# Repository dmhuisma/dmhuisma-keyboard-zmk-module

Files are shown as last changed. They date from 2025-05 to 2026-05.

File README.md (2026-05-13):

# Dmhuisma Keyboard ZMK Module

This is my ZMK module for the split keyboard I generated with the [Cosmos keyboard generator](https://ryanis.cool/cosmos/). This is version 2 of the keyboard ([version 1](https://github.com/dmhuisma/dmhuisma-keyboard-zmk-module/tree/v1) is shown in the image below as I have not built it yet). After I built [Splitcore](https://github.com/dmhuisma/splitcore-zmk) I found that I never used this one, so I decided to repurpose its parts into something new.

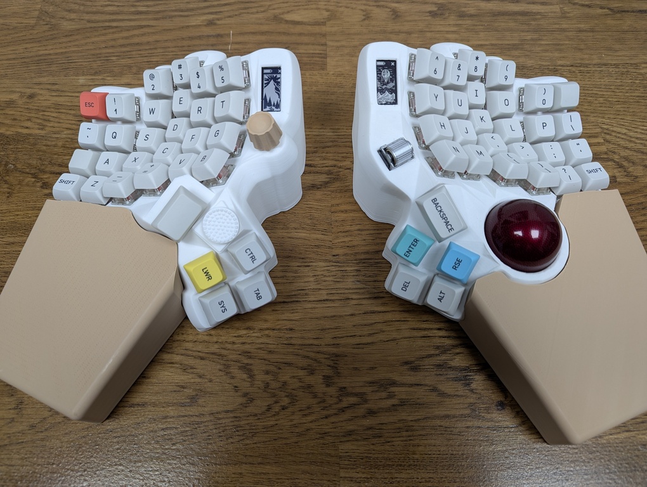
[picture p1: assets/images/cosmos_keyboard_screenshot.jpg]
Cosmos Keyboard Screenshot


The cosmos generator configuration is saved in the URL, here is [my configuration](https://ryanis.cool/cosmos/beta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).

## Features
- Ergonomic
    - Split
    - Concave key well
    - Thumb clusters
    - Staggered to accommodate my hand/finger sizes
- Trackpad
- Display
- Hotswappable keys
- Potentiometer (with directional clicking) for media controls.
- [Custom DPAD](https://github.com/dmhuisma/1u_mx_dpad) on the left side for cursor navigation or gaming.

## Building

The firmware is built by Github actions on every commit. It can also be built with a local install of ZMK with the following commands.

> west build -p auto -d build/left -b nice_nano//zmk -- -DZMK_EXTRA_MODULES="[path to module]/dmhuisma-zmk;[path to module]/zmk_arbitrary_split_data_channel;[path to module]/zmk-split-status-relay;/[path to module]/nice-view-peripheral" -DSHIELD="dmhuisma_left nice_view_peripheral"

> west build -p auto -d build/right -b nice_nano//zmk -- -DZMK_EXTRA_MODULES="[path to module]/dmhuisma-zmk;[path to module]/zmk-driver-azoteq-iqs5xx;[path to module]/zmk_arbitrary_split_data_channel;[path to module]/zmk-split-status-relay;" -DSHIELD="dmhuisma_right"

> west build -p auto -d build/dongle -b nrf52840_mdk_usb_dongle -- -DZMK_EXTRA_MODULES="[path to module]/dmhuisma-zmk;/[path to module]/zmk-pointing-acceleration-alpha;[path to module]/zmk_arbitrary_split_data_channel;[path to module]/zmk-split-status-relay" -DSHIELD="dmhuisma_dongle"

If building locally, the following external zmk modules are required on your machine:

- [zmk-driver-azoteq-iqs5xx](https://github.com/AYM1607/zmk-driver-azoteq-iqs5xx)
- [zmk-pointing-acceleration-alpha](https://github.com/nuovotaka/zmk-pointing-acceleration-alpha)
- [zmk-arbitrary-split-data-channel](https://github.com/dmhuisma/zmk_arbitrary_split_data_channel)
- [zmk-split-status-relay](https://github.com/dmhuisma/zmk-split-status-relay)
- [nice-view-battery-peripheral](https://github.com/dmhuisma/nice-view-battery-peripheral)

## Pinout

This keyboard uses the [nice!nano V2](https://nicekeyboards.com/nice-nano/) on each side. However, there is not enough GPIO pins for this keyboard, so it also uses shift registers (74HC595) for the output pins.

### Left Keyboard

#### Nice!Nano V2 Left Side GPIO
| | |
|---|---|
|Battery- ||
|**[D1]** P0.06 |RKJXT1F42001 Encoder A|
|**[D0]** P0.08 |RKJXT1F42001 Encoder B|
|GND |NiceView GND|
|GND |DPAD GND, RKJXT1F42001 GND|
|**[D2]** P0.17 |NiceView MOSI|
|**[D3]** P0.20 |RKJXT1F42001 down|
|**[D4]** P0.22 |NiceView SCK|
|**[D5]** P0.24 |74HC595 SCK|
|**[D6]** P1.00 |74HC595 MOSI|
|**[D7]** P0.11 |DPAD Up|
|**[D8]** P1.04 |DPAD Down|
|**[D9]** P1.06 |Column 4|

#### Nice!Nano V2 Right Side GPIO
| | |
|---|---|
|Battery+ ||
|Battery+ ||
|GND |74HC595 GND, 74HC595 OE|
|Reset ||
|3.3V Vcc |NiceView Vcc, 74HC595 Vcc|
|**[D21]** P0.31 (ADC)  |Row 0|
|**[D20]** P0.29 (ADC)  |Row 1|
|**[D19]** P0.02 (ADC)  |Row 2|
|**[D18]** P1.15 |Row 3|
|**[D15]** P1.13 |74HC595 CS/RCLK|
|**[D14]** P1.11 |NiceView CS|
|**[D16]** P0.10 |DPAD Left|
|**[D10]** P0.09 |DPAD Right|

#### Nice!Nano V2 Back GPIO
| | |
|---|---|
|P1.01 |RKJXT1F42001 left|
|P1.02 |RKJXT1F42001 right|
|P1.07 |Row 4|

#### Shift Register (74HC595) GPIO
| | |
|---|---|
|QA |Column 0|
|QB |Column 1|
|QC |Column 2|
|QD |Column 3|
|QE ||
|QF |Column 5|
|QG |Column 6|
|QH |Column 7|
|QH` ||

### Right Keyboard

#### Nice!Nano V2 Left Side GPIO
| | |
|---|---|
|Battery+ ||
|**[D1]** P0.06 |Trackpad reset|
|**[D0]** P0.08 |Trackpad ready|
|GND |Trackpad GND|
|GND ||
|**[D2]** P0.17 |Trackpad SDA|
|**[D3]** P0.20 |Trackpad SCL|
|**[D4]** P0.22 ||
|**[D5]** P0.24 |74HC595 SCK|
|**[D6]** P1.00 |74HC595 MOSI|
|**[D7]** P0.11 ||
|**[D8]** P1.04 ||
|**[D9]** P1.06 |Column 9|

#### Nice!Nano V2 Right Side GPIO
| | |
|---|---|
|Battery+ ||
|Battery+ ||
|GND |74HC595 GND, 74HC595 OE|
|Reset ||
|3.3V Vcc |74HC595 Vcc, Trackpad Vcc|
|**[D21]** P0.31 (ADC)  |Row 0|
|**[D20]** P0.29 (ADC)  |Row 1|
|**[D19]** P0.02 (ADC)  |Row 2|
|**[D18]** P1.15 |Row 3|
|**[D15]** P1.13 |74HC595 CS/RCLK|
|**[D14]** P1.11 ||
|**[D16]** P0.10 ||
|**[D10]** P0.09 ||

#### Nice!Nano V2 Back GPIO
| | |
|---|---|
|P1.01 ||
|P1.02 ||
|P1.07 |Row 4|

#### Shift Register (74HC595) GPIO
| | |
|---|---|
|QA |Column 8|
|QB ||
|QC |Column 10|
|QD |Column 11|
|QE |Column 12|
|QF |Column 13|
|QG |Column 14|
|QH |Column 15|
|QH` ||

### Nice!Nano V2 pinout for reference

Nice!Nano V2 Pinout

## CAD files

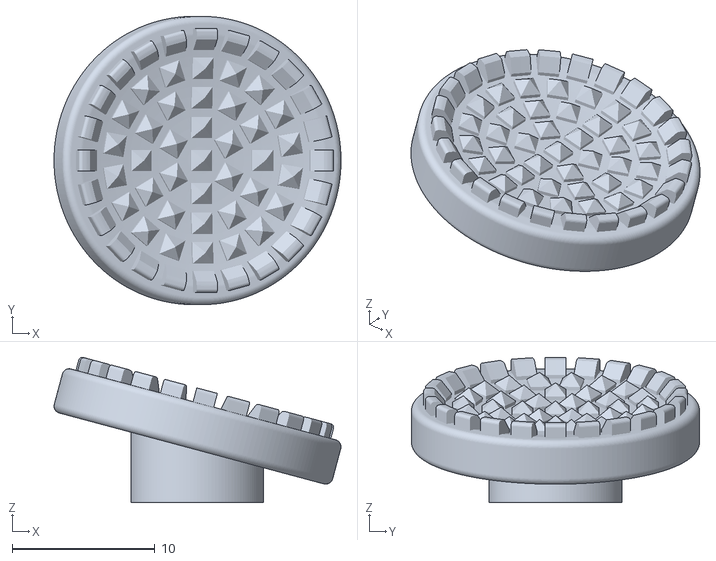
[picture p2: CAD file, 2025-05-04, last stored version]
assets/Dpad_Thumbstick.stl
20.1 x 20.2 x 10.2

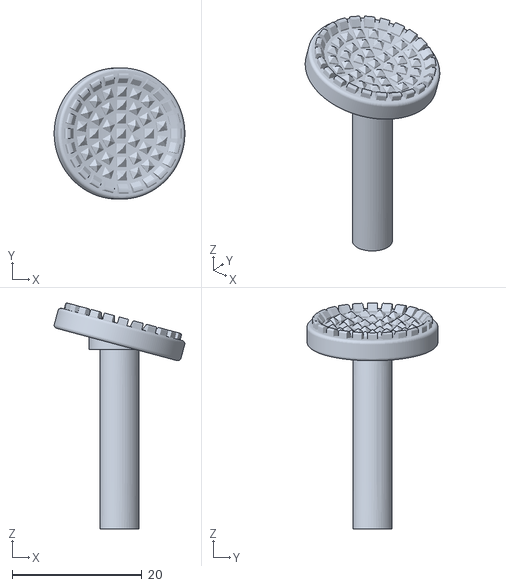
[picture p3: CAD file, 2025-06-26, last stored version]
assets/stl/dpad_joystick.stl
20.1 x 20.2 x 34.8

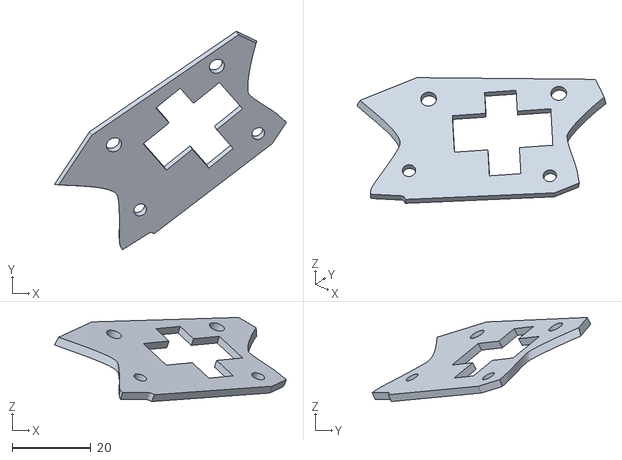
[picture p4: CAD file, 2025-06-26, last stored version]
assets/stl/dpad_pcba_holder.stl
59.1 x 55.7 x 21.4

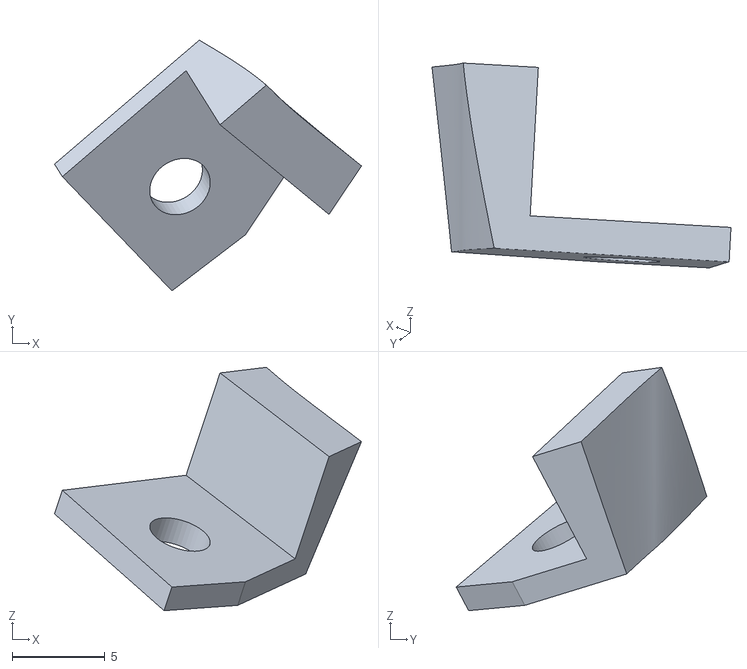
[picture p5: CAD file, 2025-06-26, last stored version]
assets/stl/pcba_holder_support_1.stl
16.5 x 13.5 x 13.1

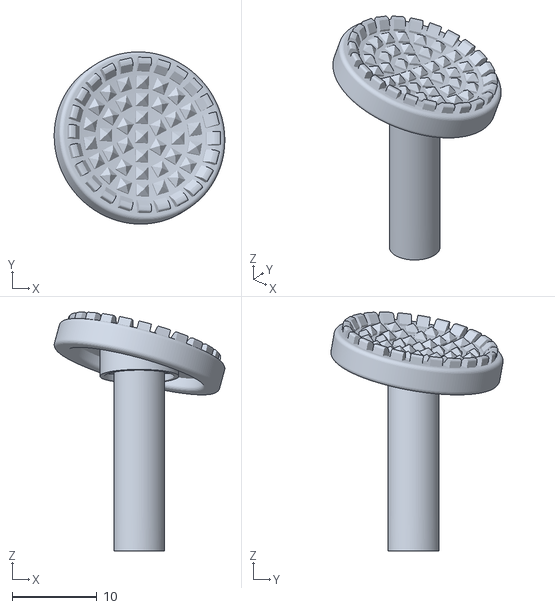
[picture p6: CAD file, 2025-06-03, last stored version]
assets/stl/Thumbstick.stl
20.1 x 20.3 x 28.2

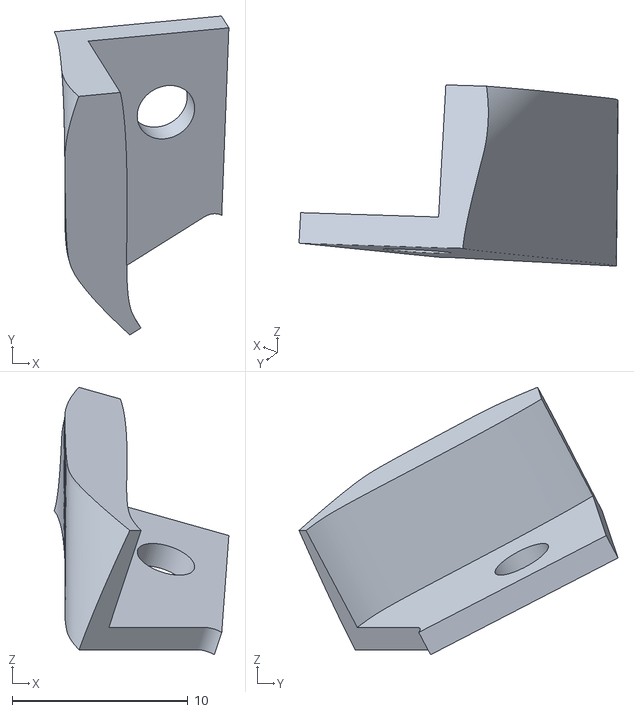
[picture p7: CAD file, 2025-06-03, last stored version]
assets/stl/pcba_holder_support_2.stl
9.94 x 18.1 x 15.2

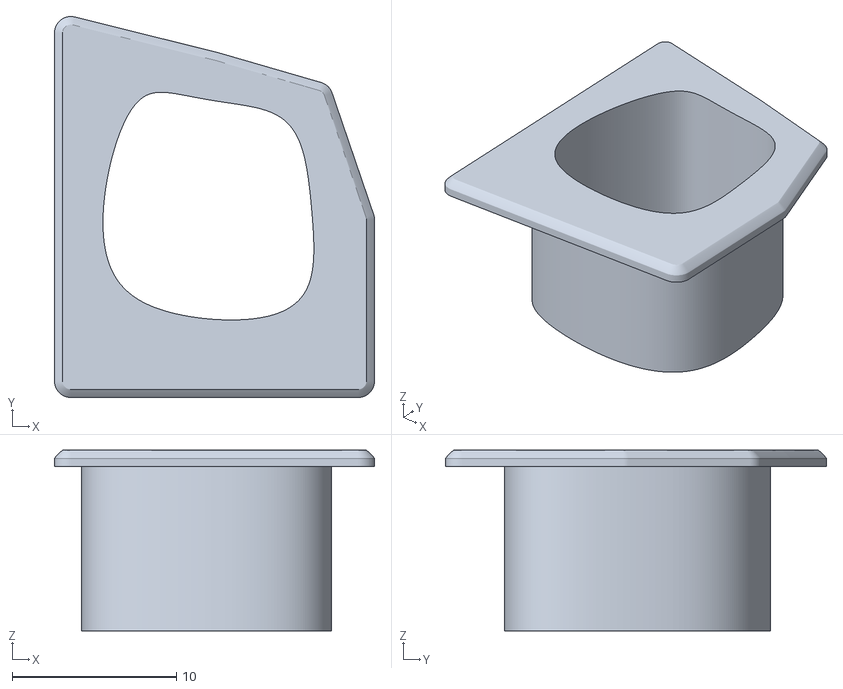
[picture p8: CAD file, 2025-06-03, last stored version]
assets/stl/dpad_hole_sleeve.stl
19.5 x 23.2 x 11.0

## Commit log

2025-04-25 Add trackball to device tree
2025-05-04 Add dpad STL, update keymap (still untested)
    [Dpad_Thumbstick.stl]
2025-06-02 encoder/keymap changes
2025-06-03 Use seeed board for dongle, add stl files
    [Dpad_Thumbstick.stl, Thumbstick.stl, dpad_hole_sleeve.stl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]
2025-06-26 keymap and joystick stl updates
    [Thumbstick.stl, dpad_joystick.stl, dpad_pcba_holder.stl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]
2025-07-24 keymap changes, LED indication for gaming layer
2025-08-16 add pointer acceleration, pin zmk version
2025-08-26 ESB battery reporting and dongle display
2025-09-26 nice-view-battery esb branch
2025-10-25 different zmk-pmw3610-driver module
2026-05-13 use separate spi for display and shift register
